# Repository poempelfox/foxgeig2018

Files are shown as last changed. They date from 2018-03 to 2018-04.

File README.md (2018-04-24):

# FoxGeig 2018

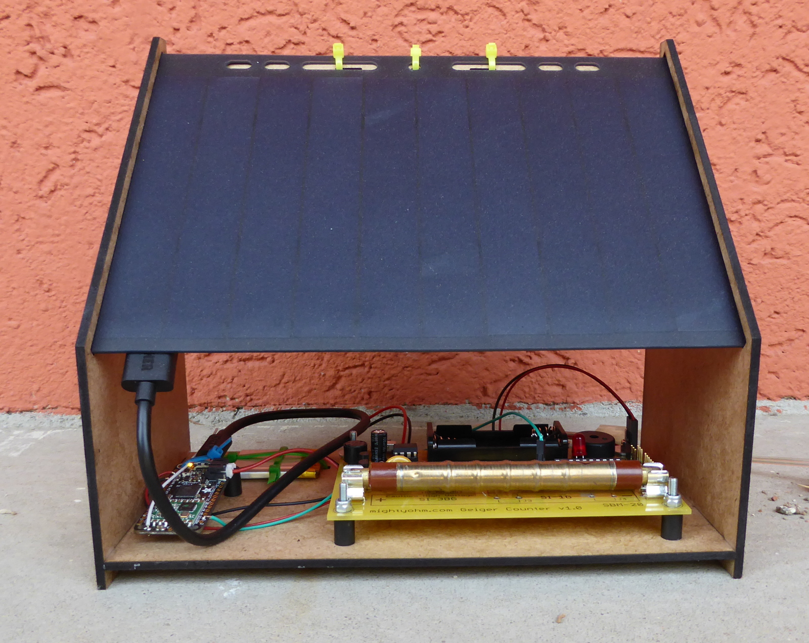
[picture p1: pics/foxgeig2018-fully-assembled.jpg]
picture of fully assembled FoxGeig2018


## Introduction

This is a geiger counter based on the [MightyOhm Geiger Counter](https://mightyohm.com/blog/products/geiger-counter/) kit. I've removed the original onboard microcontroller and instead used an Adafruit Feather 32U4 RFM69HCW, so that the measurements it makes can now be sent over the air (on 868 MHz). Because I did not want to connect it to the mains, the whole thing is solar powered. Energy is stored in a little LiPo battery, which could easily be connected because the Feather already has the necessary controller for that onboard. I've also constructed a laser-cut "case" made out of 3mm HDF (High-Density Fibreboard), although the term "case" might be a bit misleading here - it's not closed, but mostly a frame to hold the solar panel in place and the rest of the parts together. The radio-transmitted measurements are received by a [Jeelink V3](https://jeelabs.net/projects/hardware/wiki/JeeLink) and fed into [FHEM](https://fhem.de/).

## Part list

* [MightyOhm Geiger Counter](https://mightyohm.com/blog/products/geiger-counter/) kit
* "Lixada Mini 10W Solar Panel" from Amazon. This is basically a little cheap solar panel with USB output.
* Adafruit Feather 32U4 RFM69HCW (868 MHz variant)
* [480 mAh LiPo battery](https://eckstein-shop.de/LiPo-Akku-Lithium-Ion-Polymer-Batterie-37V-480mAh-JST-PH-Connector)
* 3mm HDF and a lasercutter for the case

## Power

The biggest power eater is the MightyOhm, more specifically the circuit that generates the high voltage for the Geiger Tube. Before modification, I measured its power usage at U=3.0V:
* with its onboard microcontroller:  7-8 mA avg, 15 mA peak
* without its microcontroller: 6 mA avg, 6.7 mA peak

It was therefore clear that it wasn't possible to power this from Goldcaps. Instead I bought a little Lithium Polymer battery to attach to the Adafruit Feather, which already comes prepared for that (it has a connector and all necessary electronics for charging onboard). For generating the power, I got a cheap "chinese" solar panel with USB output from Amazon. It claims to do 10W, but that value is probably more of a theoretic maximum. However, it does provide "enough" power (at least in the summer, winter hasn't been tested yet), and if there is enough sun it provides a nicely stable 5V USB power.

## Case

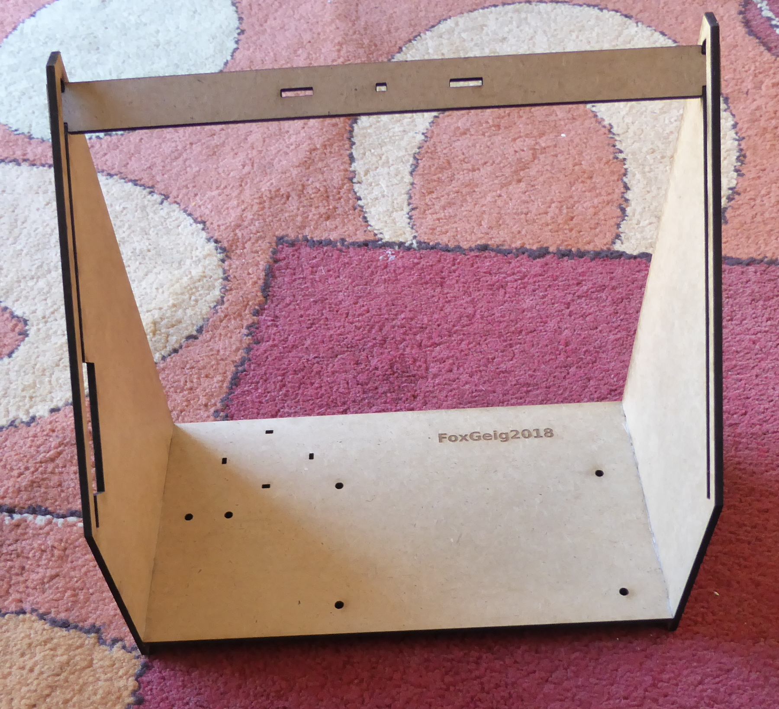
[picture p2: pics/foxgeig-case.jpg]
picture of FoxGeig2018 case


The parts for the "case" or frame were cut out of 3mm thick HDF in the [FAU Fablab](https://fablab.fau.de). They were then glued together, and after the glue had dried, the whole thing got coated with some spray wood coating.

The files for the case can be found in the "case" subdirectory in this repo.

## FAQ

Well they're not really asked _frequently_ but I'll answer them anyways.

### Why?

Why not?
Not everybody can claim to have an Geiger Counter on their balcony. Can you?

### Is it useful?

Well, it can be used to generate nice graphs that show the (natural) ambient radiation on my balcony in Erlangen, Germany. For example, on 2018-04-24 it looked like this:
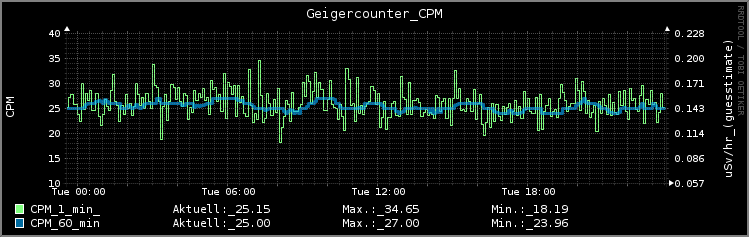
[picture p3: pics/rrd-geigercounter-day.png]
RRD graph CPM on my balcony 2018-04-24


However, if you intend to use this or the values it measures for anything serious, you're out of your mind. This is a toy, not a device to get reliable measurements.

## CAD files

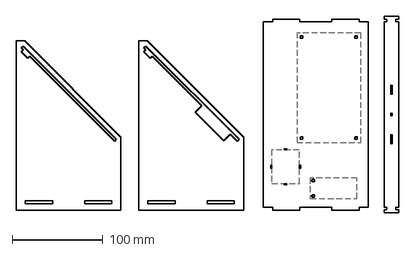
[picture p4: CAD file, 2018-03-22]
case/woodenframe.dxf
420.6 x 216.0 mm

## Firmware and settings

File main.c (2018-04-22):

/* $Id: main.c $
 * main for foxgeig2018 (Foxis Geigercounter)
 * (C) Michael "Fox" Meier 2018
 */

#include <avr/io.h>
#include <avr/interrupt.h>
#include <avr/wdt.h>
#include <avr/eeprom.h>
#include <avr/power.h>
#include <avr/sleep.h>
#include <stdio.h>
#include <string.h>
#include <util/delay.h>

#include "adc.h"
#include "eeprom.h"
#include "geiger.h"
#include "rfm69.h"
#include "lufa/console.h"

/* The values last measured */
/* Battery level. Range 0-1023, 1023 = our supply voltage * 2 = 6,6V
 * We send this shifted to the right by two as uint8_t (because the lower two
 * bits are just noise anyways) */
uint16_t batvolt = 0;
/* How often did we send a packet? */
uint32_t pktssent = 0;
/* Geigercounter values */
uint32_t geigcntavg1min = 0;
uint32_t geigcntavg60min = 0;

/* This is just a fallback value, in case we cannot read this from EEPROM
 * on Boot */
uint8_t sensorid = 3; // 0 - 255 / 0xff

/* The frame we're preparing to send. */
static uint8_t frametosend[12];

/* We need to disable the watchdog very early, because it stays active
 * after a reset with a timeout of only 15 ms. */
void dwdtonreset(void) __attribute__((naked)) __attribute__((section(".init3")));
void dwdtonreset(void) {
  MCUSR = 0;
  wdt_disable();
}

static uint8_t calculatecrc(uint8_t * data, uint8_t len)
{
  uint8_t i, j;
  uint8_t res = 0;
  for (j = 0; j < len; j++) {
    uint8_t val = data[j];
    for (i = 0; i < 8; i++) {
      uint8_t tmp = (uint8_t)((res ^ val) & 0x80);
      res <<= 1;
      if (0 != tmp) {
        res ^= 0x31;
      }
      val <<= 1;
    }
  }
  return res;
}

/* Fill the frame to send with our collected data and a CRC.
 * The protocol we use is that of a "CustomSensor" from the
 * FHEM LaCrosseItPlusReader sketch for the Jeelink.
 * So you'll just have to enable the support for CustomSensor in that sketch
 * and flash it onto a JeeNode and voila, you have your receiver.
 *
 * Byte  0: Startbyte (=0xCC)
 * Byte  1: Sensor-ID (0 - 255/0xff)
 * Byte  2: Number of data bytes that follow (6)
 * Byte  3: Sensortype (=0xf9 for FoxGeig)
 * Byte  4: CountsPerMinute for last minute, MSB
 * Byte  5: CountsPerMinute for last minute,
 * Byte  6: CountsPerMinute for last minute, LSB
 * Byte  7: CountsPerMinute for last 60 minutes, MSB
 * Byte  8: CountsPerMinute for last 60 minutes,
 * Byte  9: CountsPerMinute for last 60 minutes, LSB
 * Byte 10: Battery voltage (0-255, 255 = 6.6V)
 * Byte 11: CRC
 */
void prepareframe(void)
{
  frametosend[ 0] = 0xCC;
  frametosend[ 1] = sensorid;
  frametosend[ 2] = 8; /* 8 bytes of data follow (CRC not counted) */
  frametosend[ 3] = 0xf9; /* Sensor type: FoxGeig */
  frametosend[ 4] = (geigcntavg1min >> 16) & 0xff;
  frametosend[ 5] = (geigcntavg1min >>  8) & 0xff;
  frametosend[ 6] = (geigcntavg1min >>  0) & 0xff;
  frametosend[ 7] = (geigcntavg60min >> 16) & 0xff;
  frametosend[ 8] = (geigcntavg60min >>  8) & 0xff;
  frametosend[ 9] = (geigcntavg60min >>  0) & 0xff;
  frametosend[10] = batvolt >> 2;
  frametosend[11] = calculatecrc(frametosend, 11);
}

void loadsettingsfromeeprom(void)
{
  uint8_t e1 = eeprom_read_byte(&ee_sensorid);
  uint8_t e2 = eeprom_read_byte(&ee_invsensorid);
  if ((e1 ^ 0xff) == e2) { /* OK, the 'checksum' matches. Use this as our ID */
    sensorid = e1;
  }
}

int main(void)
{
  uint16_t lastts = 0xf000; /* This forces an update immediately after start */
  uint16_t curts;
  uint16_t tsdiff;
  uint8_t transmitinterval = 5; /* Transmitinterval in ticks of 6s, so 5 = 30s */
  
  /* Initialize stuff */
  
  loadsettingsfromeeprom();
  
  console_init();
  adc_init();
  geiger_init();
  rfm69_initport();
  /* The RFM69 needs some time to start up (5 ms according to data sheet, we wait 10 to be sure) */
  _delay_ms(10);
  rfm69_initchip();
  rfm69_setsleep(1);
  
  /* Enable watchdog timer with a timeout of 8 seconds */
  wdt_enable(WDTO_8S); /* Longest possible on ATmega328P */
  
  /* Disable unused chip parts and ports */
  /* PE6 is the IRQ line from the RFM69. We don't use it. Make sure that pin
   * is tristated on our side (it won't float, the RFM69 pulls it) */
  PORTE &= (uint8_t)~_BV(PE6);
  DDRE &= (uint8_t)~_BV(PE6);
  /* Turn off unused stuff on the AVR via PRR registers */
  /* We don't use TWI/I2C and Timer0/1 */
  PRR0 |= _BV(PRTWI) | _BV(PRTIM0) | _BV(PRTIM1);
  /* We don't use Timer4 and the USART. There seems to be a bug in
   * avr-libc on Ubuntu 16.04, it doesn't define PRTIM4 but instead
   * PRTIM2 for a nonexistant Timer2. Therefore we cannot use the
   * macro and hardcode the correct value. */
  PRR1 |= _BV(/* PRTIM4 */ 4) | _BV(PRUSART1);

  /* Prepare sleep mode */
  /* SLEEP_MODE_IDLE is the only sleepmode we can safely use. */
  set_sleep_mode(SLEEP_MODE_IDLE);
  sleep_enable();

  /* All set up, enable interrupts and go. */
  sei();

  DDRC |= (uint8_t)_BV(PC7); /* PC7 is the LED pin, drive it */
  PORTC &= (uint8_t)~_BV(PC7); /* Turn it off */

  while (1) {
    wdt_reset();
    curts = geiger_getticks();
    tsdiff = curts - lastts;
    if (tsdiff >= transmitinterval) {
      /* Time to update values and send */
      adc_power(1);
      adc_select(12);
      adc_start();
      geigcntavg1min = geiger_get1minavg();
      geigcntavg60min = geiger_get60minavg();
      batvolt = adc_read();
      adc_power(0);
      /* SEND */
      rfm69_setsleep(0);  /* This mainly turns on the oscillator again */
      prepareframe();
      console_printpgm_P(PSTR(" TX "));
      rfm69_sendarray(frametosend, 12);
      rfm69_setsleep(1);
      pktssent++;
      lastts = curts; /* Remember when we last sent a packet */
      /* We use the lower two bits of batvolt as the random noise that it is */
      uint8_t rnd = batvolt & 3;
      if (rnd == 3) {
        transmitinterval = 6;
      } else if (rnd == 0) {
        transmitinterval = 4;
      } else { /* 1 or 2 */
        transmitinterval = 5;
      }
    }
    console_work();
    if (!console_isusbconfigured()) {
      /* Don't go to sleep when USB is configured. Because then there is no
       * lack of power, and more importantly, we want the console to feel
       * "snappy" and we can't get that if we sleep for 6 seconds. */
      wdt_reset(); /* Buy us 8 seconds time because the next IRQ might only arrive in 6 seconds */
      sleep_cpu(); /* Go to sleep until the next IRQ arrives */
    }
  }
}

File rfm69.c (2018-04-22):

/* $Id: rfm69.c $
 * Functions for communication with RFM69 module
 *
 * This code was heavily copy+pasted from RFMxx.cpp in the FHEM LaCrosseIT+
 * Jeenode Firmware Code.
 */

#include <avr/io.h>
#include <avr/interrupt.h>
#include <util/delay.h>
#include <math.h>
#include "rfm69.h"
#include "lufa/console.h"

/* Pin mappings:
 *  SS     PB4
 *  MOSI   PB2
 *  MISO   PB3
 *  SCK    PB1
 *  RESET  PD4
 *  OUROWNSS PB0 (not used!)
 */
#define RFMDDR   DDRB
#define RFMPIN   PINB
#define RFMPORT  PORTB

#define RFMPIN_SS    PB4
#define RFMPIN_MOSI  PB2
#define RFMPIN_MISO  PB3
#define RFMPIN_SCK   PB1
#define RFMPIN_OURSS PB0

#define RFM_FREQUENCY 868300UL
#define RFM_DATARATE 17241.0

#define PAYLOADSIZE 64

ISR(INT6_vect)
{
  /* Nothing to do here. */
}

ISR(SPI_STC_vect)
{
  /* Nothing to do here. */
}

/* Note: Internal use only. Does not set the SS pin, the calling function
 * has to do that! */
static uint8_t rfm69_spi8(uint8_t value) {
  SPDR = value;
  /* busy-wait for transmission. this loop spins 4 usec with a 2 MHz SPI clock */
  while (!(SPSR & _BV(SPIF))) { }

  return SPDR;
}

uint16_t rfm69_spi16(uint16_t value) {
  _delay_us(1);
  RFMPORT &= (uint8_t)~_BV(RFMPIN_SS);
  _delay_us(1);
  uint16_t reply = rfm69_spi8(value >> 8) << 8;
  reply |= rfm69_spi8(value & 0xff);
  _delay_us(1);
  RFMPORT |= _BV(RFMPIN_SS);
  _delay_us(1);
  
  return reply;
}

uint8_t rfm69_readreg(uint8_t reg) {
  return rfm69_spi16(((uint16_t)(reg & 0x7f) << 8) | 0x00) & 0xff;
}

static void rfm69_writereg(uint8_t reg, uint8_t val) {
  rfm69_spi16(((uint16_t)(reg | 0x80) << 8) | val);
}

void rfm69_clearfifo(void) {
  /* There is no need for reading / ORing the register here because all
   * bits except the FiFoOverrun-bit we set to clear the FIFO are read-only */
  rfm69_writereg(0x28, (1 << 4)); /* RegIrqFlags2 */
}

void rfm69_settransmitter(uint8_t e) {
  if (e) {
    /* RegOpMode => TRANSMIT */
    rfm69_writereg(0x01, (rfm69_readreg(0x01) & 0xE3) | 0x0C);
  } else {
    /* RegOpMode => STANDBY */
    rfm69_writereg(0x01, (rfm69_readreg(0x01) & 0xE3) | 0x04);
  }
}

void rfm69_setsleep(uint8_t s) {
  if (s) {
    /* RegOpMode => SLEEP */
    rfm69_writereg(0x01, (rfm69_readreg(0x01) & 0xE3) | 0x00);
  } else {
    /* RegOpMode => STANDBY */
    rfm69_writereg(0x01, (rfm69_readreg(0x01) & 0xE3) | 0x04);
    while (!(rfm69_readreg(0x27) & 0x80)) { /* Wait until ready */ }
  }
}

void rfm69_sendarray(uint8_t * data, uint8_t length) {
  /* Set the length of our payload */
  rfm69_writereg(0x38, length);
  rfm69_clearfifo(); /* Clear the FIFO */
  /* Now fill the FIFO. We manually set SS and use spi8 because this
   * is the only "register" that is larger than 8 bits. */
  _delay_us(1);
  RFMPORT &= (uint8_t)~_BV(RFMPIN_SS);
  _delay_us(1);
  rfm69_spi8(0x80); /* Select RegFifo (0x00) for writing (|0x80) */
  for (int i = 0; i < length; i++) {
    rfm69_spi8(data[i]);
  }
  _delay_us(1);
  RFMPORT |= _BV(RFMPIN_SS);
  _delay_us(1);
  /* FIFO has been filled. Tell the RFM69 to send by just turning on the transmitter. */
  rfm69_settransmitter(1);
  /* Wait for transmission to finish, visible in RegIrqFlags2. */
  uint8_t reg28 = 0x00;
  uint16_t maxreps = 10000;
  while (!(reg28 & 0x08)) {
    reg28 = rfm69_readreg(0x28);
    maxreps--;
    if (maxreps == 0) {
      console_printpgm_P(PSTR("![TX TIMED OUT]!"));
      break;
    }
  }
  rfm69_settransmitter(0);
}

void rfm69_initport(void) {
  /* Configure Pins for output / input */
  /* on the feather, the RESET pin of the RFM is connected to PD4. Trigger a
   * reset by pulling the RESET pin HIGH for at least 100us. */
  DDRD |= _BV(PD4);
  PORTD |= _BV(PD4);
  /* Now the rest of the I/O pins */
  RFMDDR |= _BV(RFMPIN_MOSI);
  RFMDDR &= (uint8_t)~_BV(RFMPIN_MISO);
  RFMDDR |= _BV(RFMPIN_SCK);
  RFMDDR |= _BV(RFMPIN_SS);
  /* We do not really use the SS pin of the AVR, but if it were pulled low,
   * the AVR would drop out of master mode! To avoid this, we configure it as
   * output pin. */
  RFMDDR |= _BV(RFMPIN_OURSS);

  RFMPORT |= _BV(RFMPIN_SS);
  
  /* Enable hardware SPI, no need to manually do it.
   * set master mode with rate clk/4 = 2 MHz (maximum of RFM69 is unknown) */
  SPCR = _BV(SPE) | _BV(MSTR);
  SPSR = 0x00; /* To set SPI2X to 0, rest is read-only anyways */
  
  _delay_us(200); /* 100us minimum time the RESET pin needs to be pulled high on the RFM */
  PORTD &= (uint8_t)~_BV(PD4);
}
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

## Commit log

2018-03-09 add support for ADC and measure the lipo battery voltage through the pin provided on the feather ("A9" in Arduino speak but really ADC12 - WTF do they have to renumber these?!)
2018-03-10 store all 10 bits of batvolt coming from ADC, shorten value to 8 bit only on transmission.
    [main.c]
2018-03-10 working on adding the RFM69 radio module (not working yet)
    [main.c, rfm69.c]
2018-03-10 fix RFM69 initialization. We can now properly talk to the RFM and receive replies. Sendings still doesn't work, still searching for the "why".
    [main.c, rfm69.c]
2018-03-11 add geiger.c (currently just containing a 30 second timer)
2018-03-12 use tick counter to update and transmit values every 30s (even if that still does not work)
    [main.c]
2018-03-14 remove return value of console_work() again, this does not work well. Instead, query if USB is configured, and if it is, do not sleep at all - this guarantees a snappy console when plugged in to a PC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
    [main.c]
2018-03-18 sending works if, and only if, we use PA1 instead of PA0. I'm pretty sure I've tried this before and it didn't, but as long as it works, I'm not really interested in solving the mystery anymore.
    [rfm69.c]
2018-03-18 fix description of packet contents
    [main.c]
2018-03-22 first attempt to construct a "case" (more like a holder)
    [woodenframe.dxf]
2018-03-22 inkscape variant of "case", (hopefully) ready to be lasercut from 3mm HDF
